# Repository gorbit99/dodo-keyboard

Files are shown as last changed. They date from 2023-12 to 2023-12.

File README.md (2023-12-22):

# Dodo

Dodo is a 60%, low-profile, wireless mechanical keyboard with per-key RGB
backlighting a display and a rotary encoder.

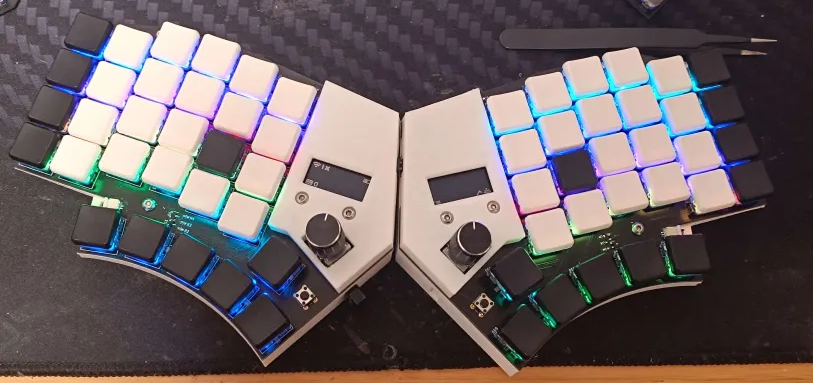
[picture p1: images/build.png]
The build


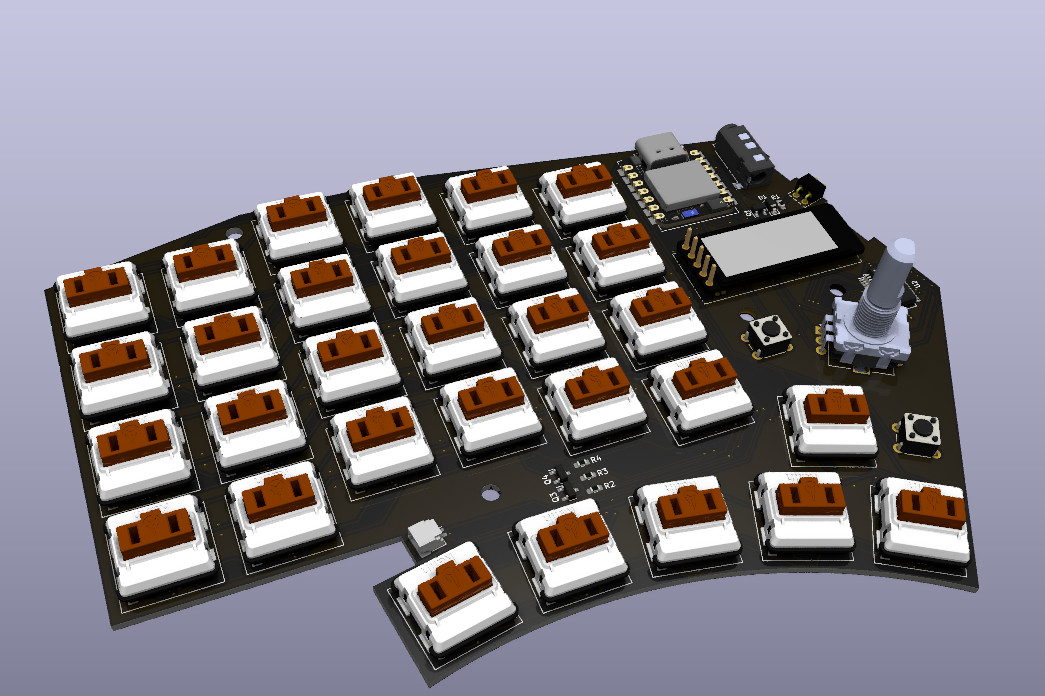
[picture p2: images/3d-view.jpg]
3D render of the PCB


## BOM

To build the PCB, you will need the following components for each side (so make
sure to get double of each):

| Part | Count | Link |
| --- | ----: | --- |
| B5817W Diode | 1 | [AliExpress](https://www.aliexpress.com/item/1005005615035910.html) |
| SK6812 MINI-E <sup>1</sup> | 30 | [AliExpress](https://www.aliexpress.com/item/1005005248164351.html) |
| 1N4148 SOD-123 | 30 | [AliExpress](https://www.aliexpress.com/item/1005005271390029.html) |
| SMD 3.5 mm jack <sup>2</sup> | 1 | [AliExpress](https://www.aliexpress.com/item/4000661908135.html) |
| 2 pin POGO connector <sup>2</sup> | 1 | [AliExpress](https://www.aliexpress.com/item/1005002006325514.html) |
| AO3401A <sup>1</sup> | 2 | [AliExpress](https://www.aliexpress.com/item/4001197981239.html) |
| 2N7002 <sup>1</sup> | 1 | [AliExpress](https://www.aliexpress.com/item/1005004759627915.html) |
| 10k Ω 0603 resistor <sup>1</sup>  | 3 | [AliExpress](https://www.aliexpress.com/item/1005006142628179.html) |
| 560 Ω 0603 resistor <sup>1</sup>  | 2 | [AliExpress](https://www.aliexpress.com/item/1005006142628179.html) |
| Momentary tactile switch | 2 | [AliExpress](https://www.aliexpress.com/item/1005004159746274.html) |
| EC11E style encoder <sup>3</sup>  | 1 | [AliExpress](https://www.aliexpress.com/item/1005002358274622.html) |
| Kailh Choc V1 | 30 | [AliExpress](https://www.aliexpress.com/item/1005004522163996.html) |
| XIAO BLE <sup>4</sup> | 1 | [AliExpress](https://www.aliexpress.com/item/1005004459618789.html) |
| MCP23S17SS | 1 | [AliExpress](https://www.aliexpress.com/item/1005004925908454.html) |
| nice!view <sup>5</sup> | 1 | [Official nice!view site](https://nicekeyboards.com/nice-view/) |
| SMD JST SH connector | 1 | [AliExpress](https://www.aliexpress.com/item/1005005682408443.html) |

All links are examples, I recommend looking around for better orders, and
especially switches that you like

1: The following components can be omitted, if you don't want RGB: SK6812
MINI-E, 1xAO3401A, 2N7002, 2x10k resistor, 1x560R resistor

2: These are for power delivery (only!) between the halves, so you can charge
them at the same time, but they are technically optional

3: Optional, if you don't need an encoder

4: You might find these as "XIAO NRF52840" or similar. There is also a sense
variant which is more expensive and not necessary

5: Optional, if you don't need a display

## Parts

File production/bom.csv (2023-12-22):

Designator | Footprint | Quantity | Value | LCSC Part #
BT1 | JST_SH_SM02B-SRSS-TB_1x02-1MP_P1.00mm_Horizontal_Double | 1 | Battery_Cell
D1 | D_SOD-123_Double | 1 | D_Schottky
D10, D12, D14, D16, D18, D2, D20, D22, D24, D26, D28, D30, D32, D34, D36, D38, D4, D40, D42, D44, D46, D48, D50, D52, D54, D56, D58, D6, D60, D8 | SK6812MINI-E_Double | 30 | SK6812MINI-E
D11, D13, D15, D17, D19, D21, D23, D25, D27, D29, D3, D31, D33, D35, D37, D39, D41, D43, D45, D47, D49, D5, D51, D53, D55, D57, D59, D61, D7, D9 | D_SOD-123_Double | 30 | 1N4148
H1, H2, H3, H4 | MountingHole_3.2mm_M3 | 4 | MountingHole
J1 | Jack_3.5mm_KoreanHropartsElec_PJ-320D-4A_Horizontal_Double | 1 | AudioJack4
J2 | Pogo2-Right-Angle | 1 | Conn_01x02_Socket
JP1, JP2, JP3, JP4 | Double_Sided_Jumper | 4 | SolderJumper_3_Open
Q1, Q4 | SOT-23_Double | 2 | AO3401A
Q3 | SOT-23_Double | 1 | 2N7002
R1, R3, R4 | 0603 | 3 | 10k
R2, R5 | 0603 | 2 | 560R
SW1, SW2 | SW_PUSH_6mm_Double | 2 | SW_Push
SW10, SW11, SW12, SW13, SW14, SW15, SW16, SW17, SW18, SW19, SW20, SW21, SW22, SW23, SW24, SW25, SW26, SW27, SW28, SW29, SW30, SW31, SW32, SW33, SW4, SW5, SW6, SW7, SW8, SW9 | SW_Kailh_Choc_V1_1.00u_Double | 30 | SW_Push
SW3 | RotaryEncoder_Alps_EC11E-Switch_Vertical_H20mm_Double | 1 | RotaryEncoder_Switch
U1 | XIAO-nRF52840_Double | 1 | XIAO_nRF52840
U2 | SSOP-28_5.3x10.2mm_P0.65mm_Double | 1 | MCP23S17_SS
U3 | NICE_VIEW | 1 | NICE_VIEW

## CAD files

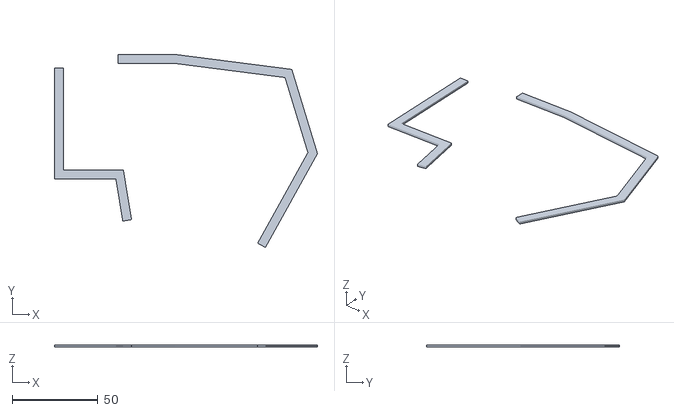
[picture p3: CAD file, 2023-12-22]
Case/DodoCasev3-Feet.stl
153.3 x 112.5 x 1.40

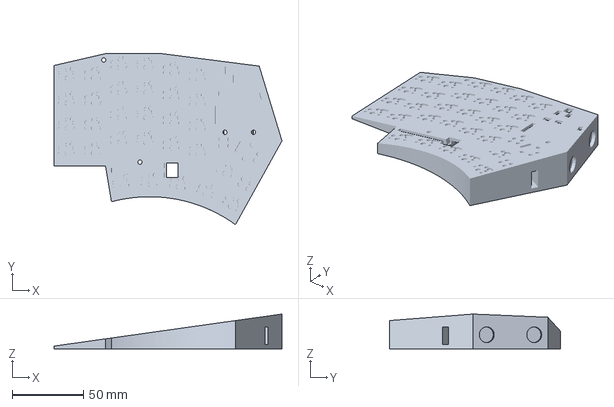
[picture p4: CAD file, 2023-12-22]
Case/DodoCasev3-Base.3mf
160.3 x 120.5 x 24.5 mm

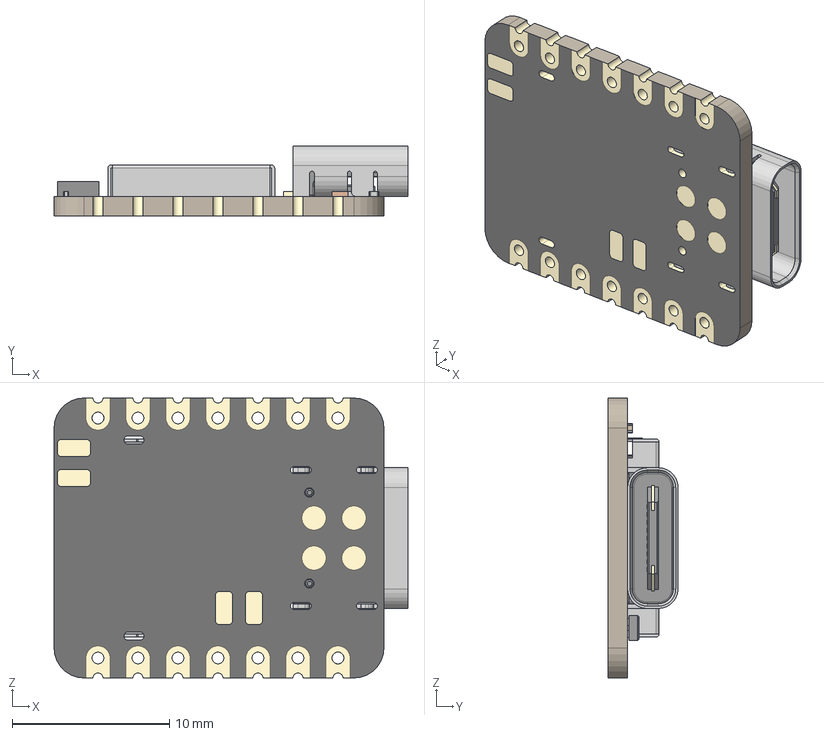
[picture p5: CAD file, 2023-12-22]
custom_parts/XIAO-nRF52840 v15.step
22.5 x 4.46 x 17.8 mm
BOSS-EXTRUDE14_8_
BOSS-EXTRUDE7_4_
BOSS-EXTRUDE7_3_
BOSS-EXTRUDE14_4_
BOSS-EXTRUDE14_2_
BOSS-EXTRUDE14_11_
BOSS-EXTRUDE7_7_
BOSS-EXTRUDE14_9_
BOSS-EXTRUDE14_3_
BOSS-EXTRUDE14_7_
MIRROR2
BOSS-EXTRUDE14_5_
BOSS-EXTRUDE14_12_
BOSS-EXTRUDE7_8_
BOSS-EXTRUDE7_1_
BOSS-EXTRUDE14_10_
BOSS-EXTRUDE7_9_
BOSS-EXTRUDE14_6_
BOSS-EXTRUDE14_1_
BOSS-EXTRUDE7_6_
BOSS-EXTRUDE7_2_
CUT-EXTRUDE5
BOSS-EXTRUDE7_5_
Shield
Pins
CAP x 2
ANT1
Silkscreen
CAP 3
LED
USR
2 v1

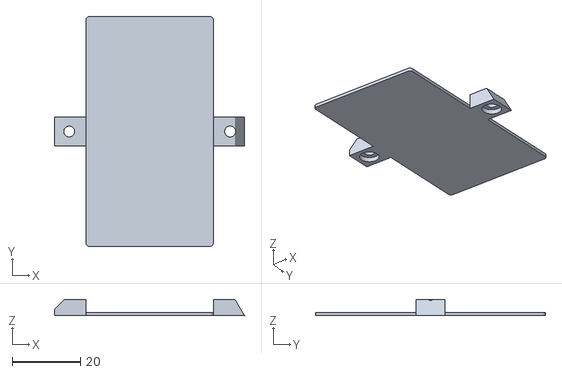
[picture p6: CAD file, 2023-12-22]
Case/DodoCasev3-BatteryCover.stl
55.5 x 67.2 x 4.80

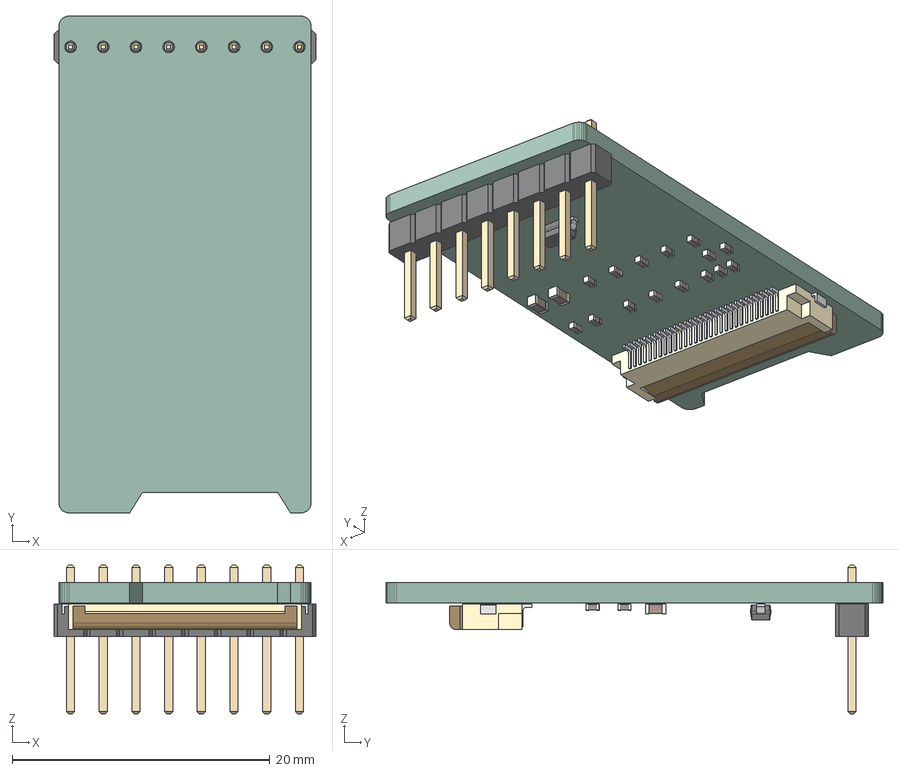
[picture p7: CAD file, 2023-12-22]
custom_parts/epaper-102.step
20.3 x 38.6 x 11.5 mm
_autosave-epaper-102 PCB

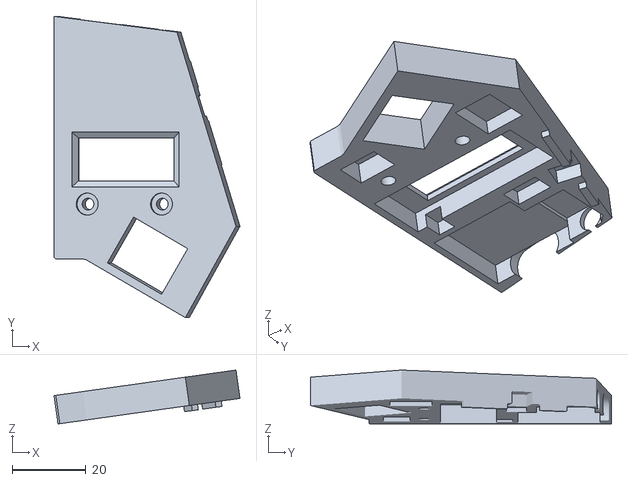
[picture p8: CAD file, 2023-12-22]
Case/DodoCasev3-Top.stl
50.4 x 81.5 x 14.6

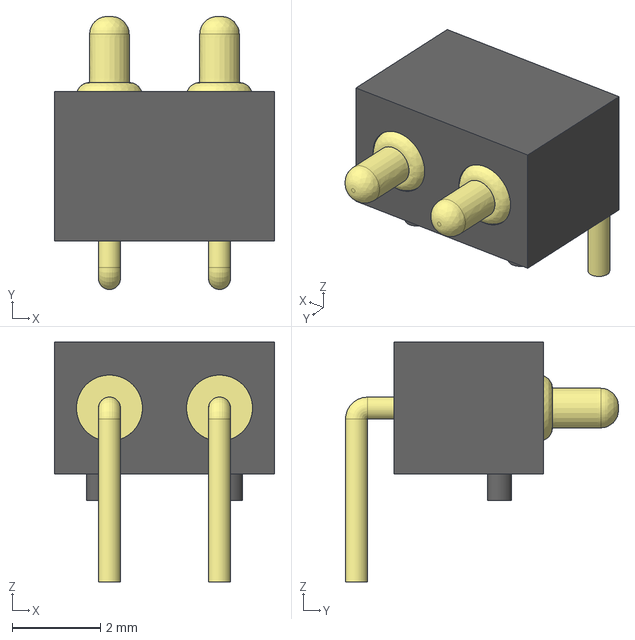
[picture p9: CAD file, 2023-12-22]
custom_parts/RightAnglePogo2_Male.step
5.00 x 6.20 x 5.45 mm
Pins

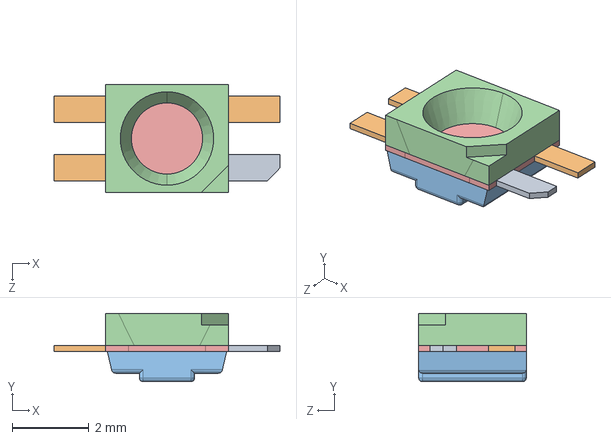
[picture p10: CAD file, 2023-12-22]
custom_parts/SK6812MINI-E.stp
5.88 x 1.78 x 2.80 mm

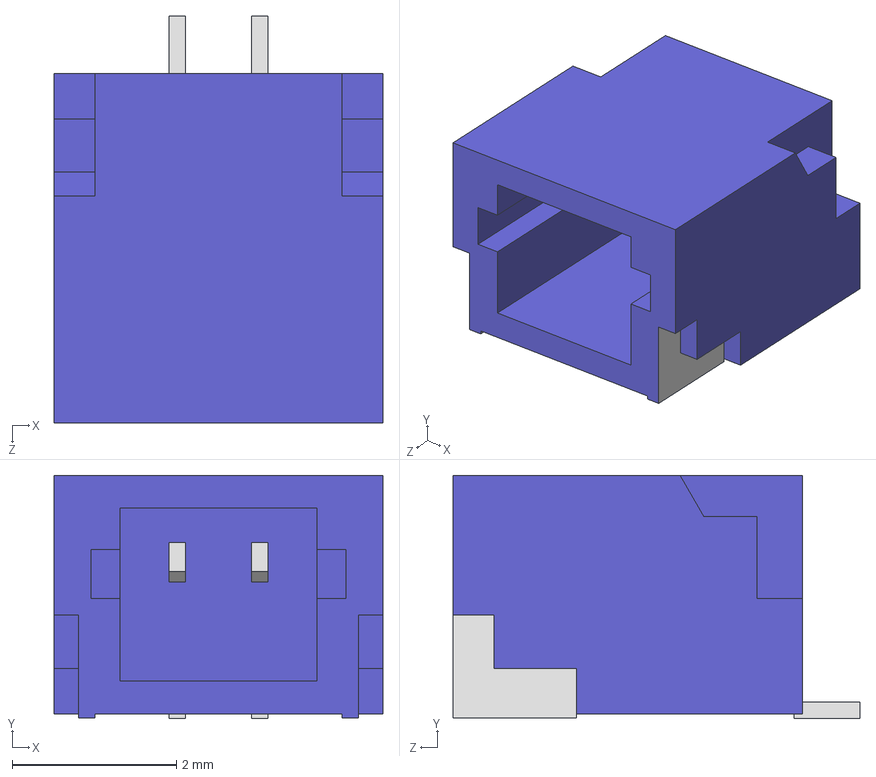
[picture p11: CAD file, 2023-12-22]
custom_parts/SM02B-SRSS-TB.STEP
4.00 x 2.96 x 4.95 mm

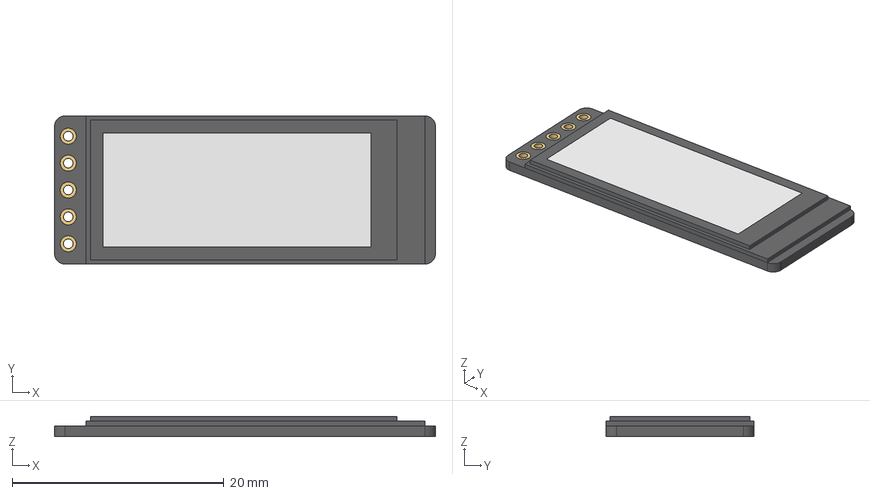
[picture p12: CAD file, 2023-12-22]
custom_parts/NiceView.step
36.0 x 14.0 x 1.90 mm
Screen
ScreenEdge
DisplayBody
Pins

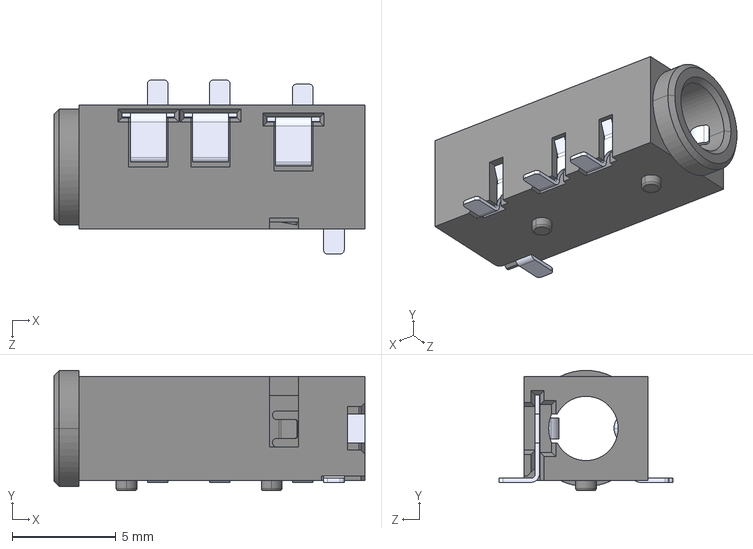
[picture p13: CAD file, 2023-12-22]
custom_parts/SJ2-3574A-SMT-TR--3DModel-STEP-56544.STEP
15.0 x 5.80 x 8.40 mm

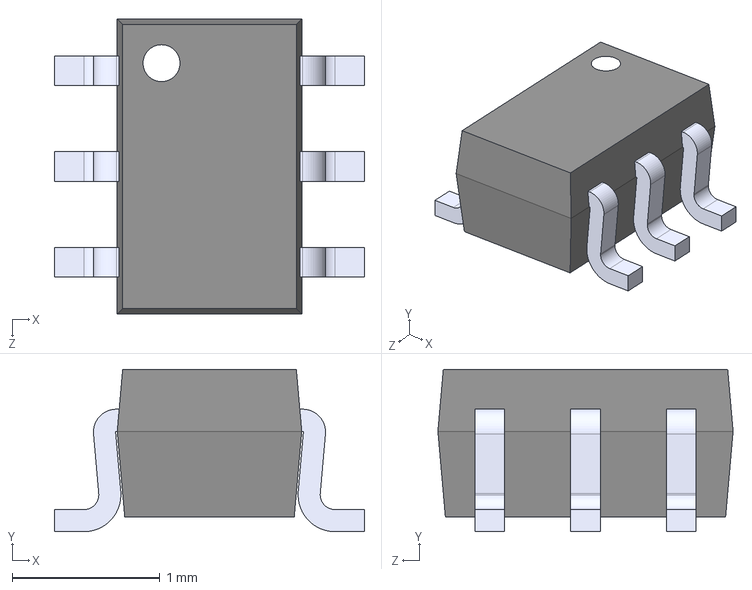
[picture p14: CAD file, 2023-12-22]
custom_parts/SMF05CT1G.step
2.10 x 1.10 x 2.00 mm

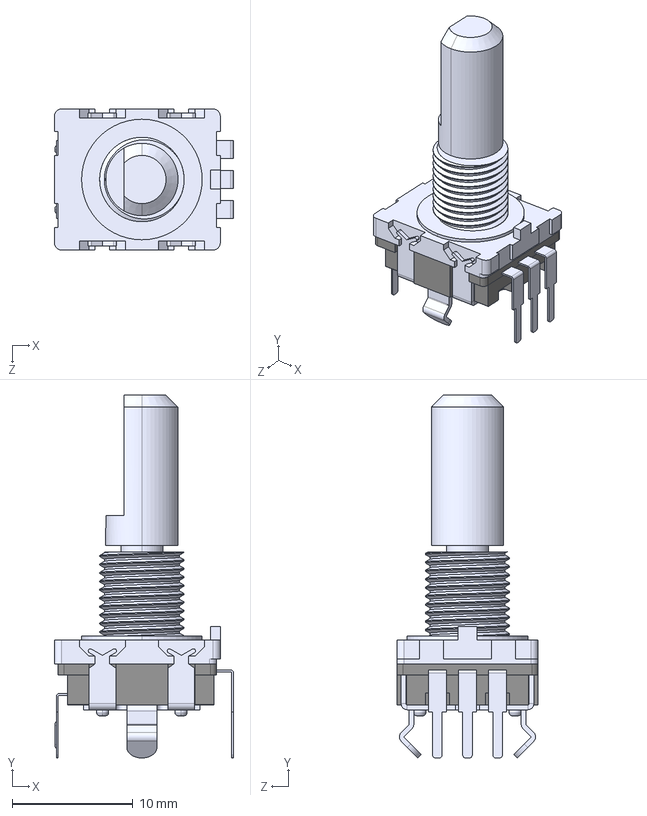
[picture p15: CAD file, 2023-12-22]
custom_parts/482016514001--3DModel-STEP-56544.STEP
14.9 x 30.1 x 11.7 mm

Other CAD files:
custom_parts/NiceView.stl
custom_parts/SM02B-SRSS-TB.step

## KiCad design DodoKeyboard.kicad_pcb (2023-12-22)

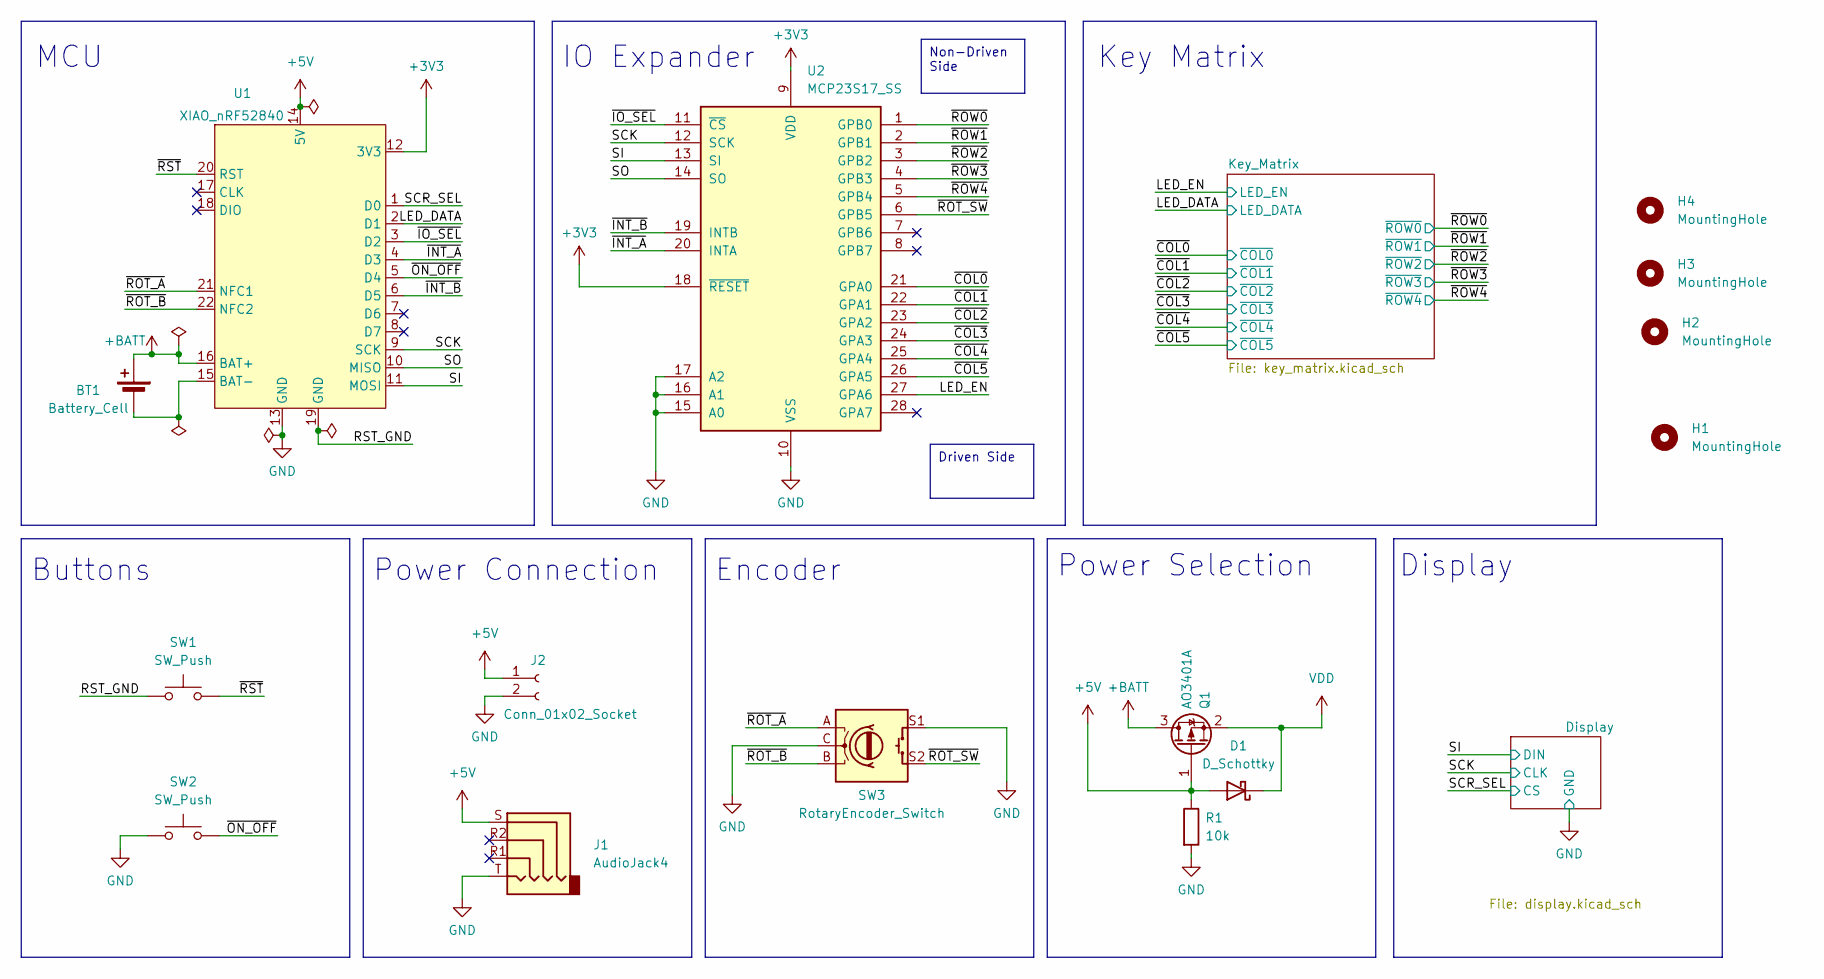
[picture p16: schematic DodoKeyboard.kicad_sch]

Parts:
BT1: Battery_Cell; JST_SH_SM02B-SRSS-TB_1x02-1MP_P1.00mm_Horizontal_Double
D1: D_Schottky; D_SOD-123_Double
H1, H2, H3, H4: MountingHole; MountingHole_3.2mm_M3
J1: AudioJack4; Jack_3.5mm_KoreanHropartsElec_PJ-320D-4A_Horizontal_Double
J2: Conn_01x02_Socket; Pogo2-Right-Angle
Q1: AO3401A; SOT-23_Double
R1: 10k; R_0603_1608Metric_Pad0.98x0.95mm_HandSolder_Double
SW1, SW2: SW_Push; SW_PUSH_6mm_Double
SW3: RotaryEncoder_Switch; RotaryEncoder_Alps_EC11E-Switch_Vertical_H20mm_Double
U1: XIAO_nRF52840; XIAO-nRF52840_Double
U2: MCP23S17_SS; SSOP-28_5.3x10.2mm_P0.65mm_Double

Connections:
+3V3: U1.12 (3V3), U2.9 (VDD), U2.18 (~RESET); also elsewhere on the board
+5V: D1.2 (A), J1.S, J2.1, Q1.1 (G), R1.1, U1.14 (5V)
+BATT: BT1.1 (+), Q1.3 (D), U1.16 (BAT+)
/LED_DATA: U1.2 (D1); also elsewhere on the board
/LED_EN: U2.27 (GPA6); also elsewhere on the board
/RST_GND: SW1.1, U1.19 (GND)
/SCK: U1.9 (SCK), U2.12 (SCK); also elsewhere on the board
/SCR_SEL: U1.1 (D0); also elsewhere on the board
/SI: U1.11 (MOSI), U2.13 (SI); also elsewhere on the board
/SO: U1.10 (MISO), U2.14 (SO)
/~COL0: U2.21 (GPA0); also elsewhere on the board
/~COL1: U2.22 (GPA1); also elsewhere on the board
/~COL2: U2.23 (GPA2); also elsewhere on the board
/~COL3: U2.24 (GPA3); also elsewhere on the board
/~COL4: U2.25 (GPA4); also elsewhere on the board
/~COL5: U2.26 (GPA5); also elsewhere on the board
/~INT_A: U1.4 (D3), U2.20 (INTA)
/~INT_B: U1.6 (D5), U2.19 (INTB)
/~IO_SEL: U1.3 (D2), U2.11 (~CS)
/~ON_OFF: SW2.2, U1.5 (D4)
/~ROT_A: SW3.A, U1.21 (NFC1)
/~ROT_B: SW3.B, U1.22 (NFC2)
/~ROT_SW: SW3.S2, U2.6 (GPB5)
/~ROW0: U2.1 (GPB0); also elsewhere on the board
/~ROW1: U2.2 (GPB1); also elsewhere on the board
/~ROW2: U2.3 (GPB2); also elsewhere on the board
/~ROW3: U2.4 (GPB3); also elsewhere on the board
/~ROW4: U2.5 (GPB4); also elsewhere on the board
/~RST: SW1.2, U1.20 (RST)
GND: J1.T, J2.2, R1.2, SW2.1, SW3.C, SW3.S1, U1.13 (GND), U2.10 (VSS), U2.15 (A0), U2.16 (A1), U2.17 (A2); also elsewhere on the board
unnamed: BT1.2 (-), U1.15 (BAT-)
VDD: D1.1 (K), Q1.2 (S); also elsewhere on the board

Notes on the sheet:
Non-Driven Side
Driven Side
Display
Power Connection
Buttons
MCU
Encoder
Key Matrix
Power Selection
IO Expander

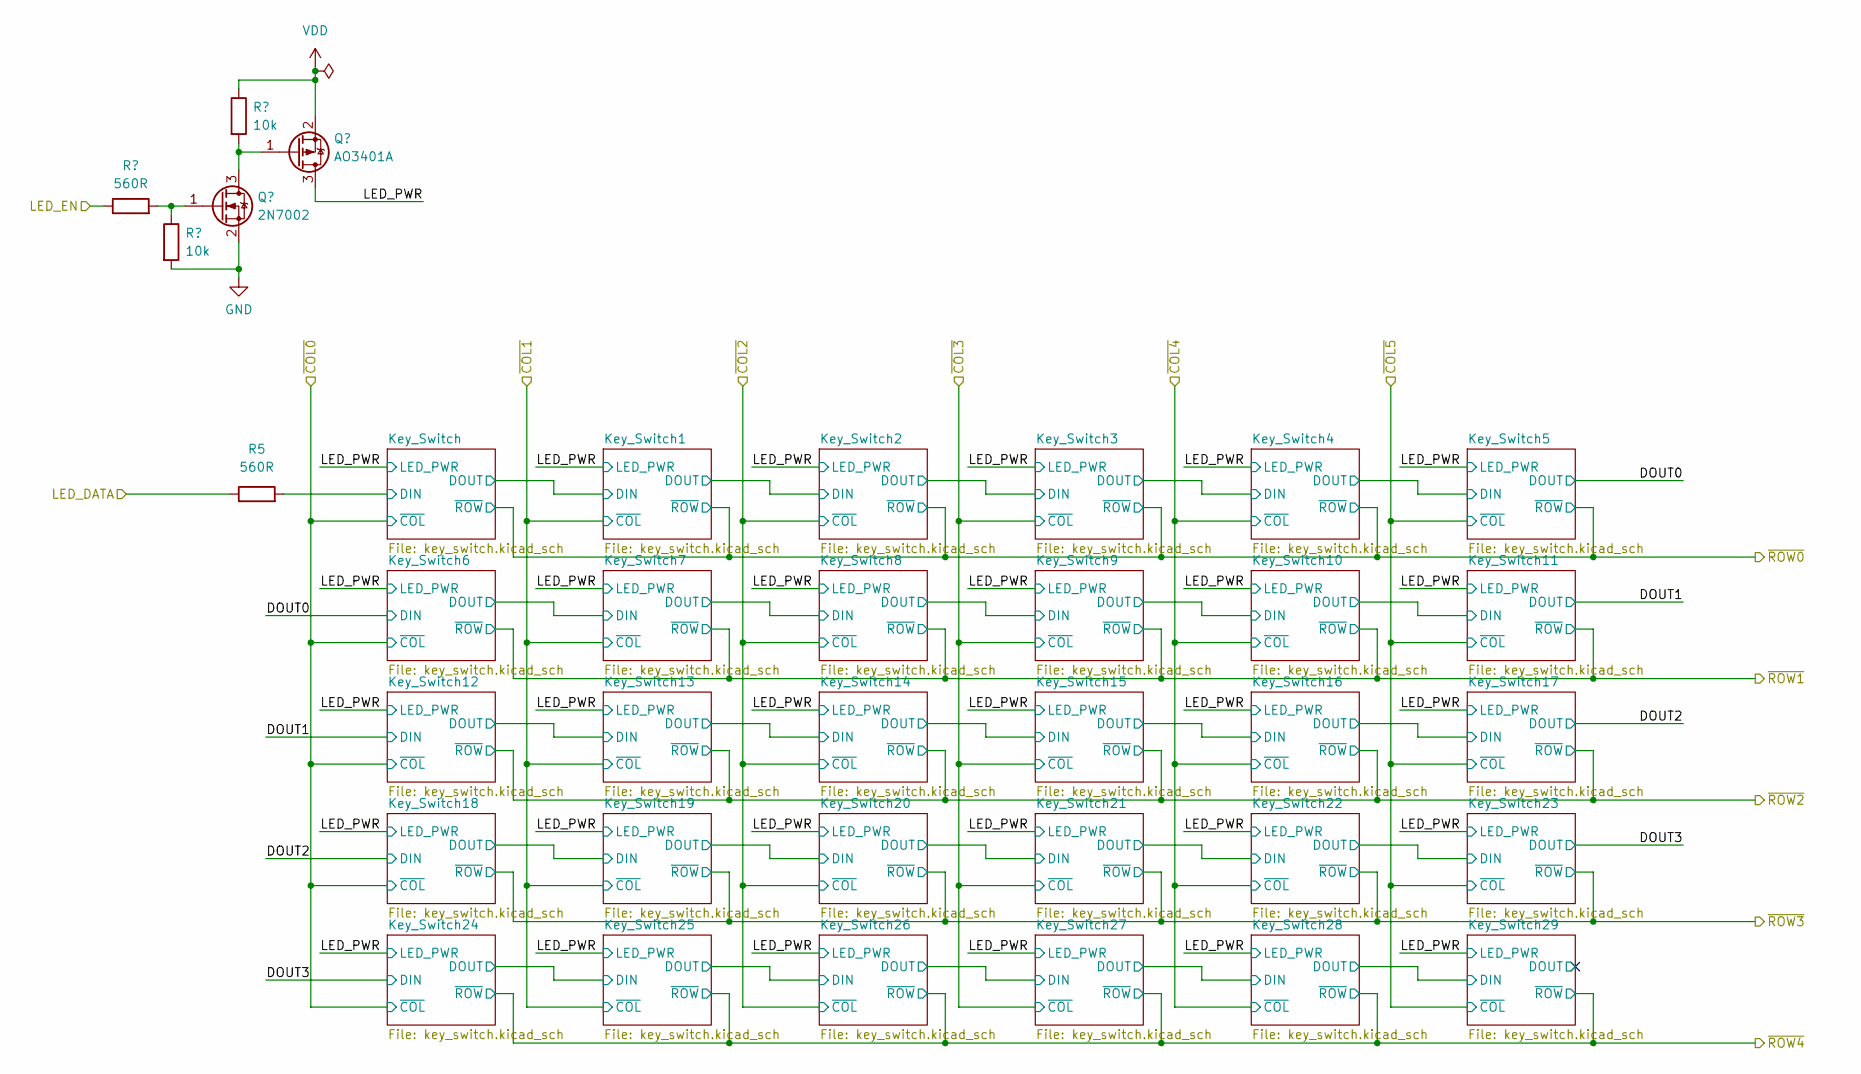
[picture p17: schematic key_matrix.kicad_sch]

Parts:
Q3: 2N7002; SOT-23_Double
Q4: AO3401A; SOT-23_Double
R2, R5: 560R; R_0603_1608Metric_Pad0.98x0.95mm_HandSolder_Double
R3, R4: 10k; R_0603_1608Metric_Pad0.98x0.95mm_HandSolder_Double

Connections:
/Key_Matrix/Key_Switch/DIN: R5.2; also elsewhere on the board
/Key_Matrix/LED_PWR: Q4.3 (D); also elsewhere on the board
/LED_DATA: R5.1; also elsewhere on the board
/LED_EN: R2.1; also elsewhere on the board
GND: Q3.2 (S), R3.2; also elsewhere on the board
unnamed: Q3.3 (D), Q4.1 (G), R4.2
unnamed: Q3.1 (G), R2.2, R3.1
VDD: Q4.2 (S), R4.1; also elsewhere on the board

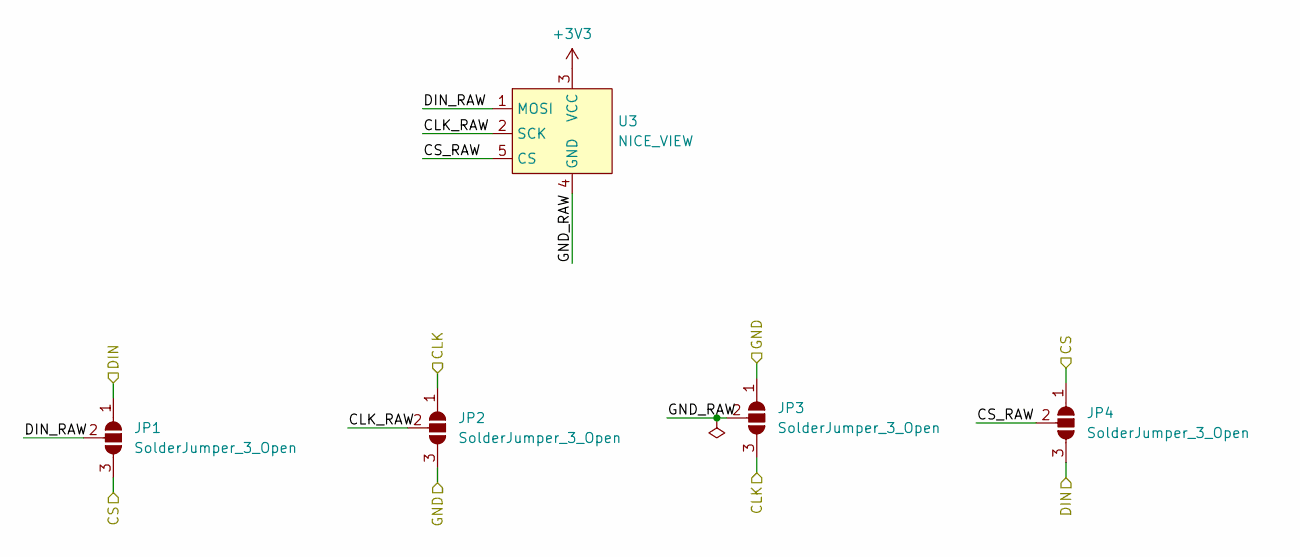
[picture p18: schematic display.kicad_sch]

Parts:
JP1, JP2, JP3, JP4: SolderJumper_3_Open; Double_Sided_Jumper
U3: NICE_VIEW

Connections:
+3V3: U3.3 (VCC); also elsewhere on the board
/Display/CLK_RAW: JP2.2 (C), U3.2 (SCK)
/Display/CS_RAW: JP4.2 (C), U3.5 (CS)
/Display/DIN_RAW: JP1.2 (C), U3.1 (MOSI)
/Display/GND_RAW: JP3.2 (C), U3.4 (GND)
/SCK: JP2.1 (A), JP3.3 (B); also elsewhere on the board
/SCR_SEL: JP1.3 (B), JP4.1 (A); also elsewhere on the board
/SI: JP1.1 (A), JP4.3 (B); also elsewhere on the board
GND: JP2.3 (B), JP3.1 (A); also elsewhere on the board

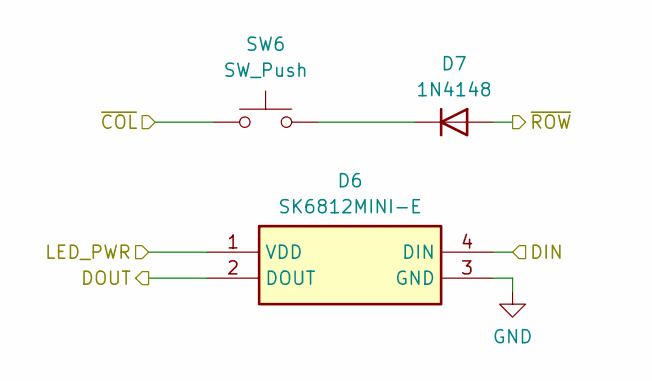
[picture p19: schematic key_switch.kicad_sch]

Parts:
D6: SK6812MINI-E; SK6812MINI-E_Double; Manufacturer_Part_Number SK6812MINI-E
D7: 1N4148; D_SOD-123_Double
SW6: SW_Push; SW_Kailh_Choc_V1_1.00u_Double

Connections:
/Key_Matrix/Key_Switch1/DOUT: D6.4 (DIN); also elsewhere on the board
/Key_Matrix/Key_Switch2/DOUT: D6.2 (DOUT); also elsewhere on the board
/Key_Matrix/LED_PWR: D6.1 (VDD); also elsewhere on the board
/~COL2: SW6.1; also elsewhere on the board
/~ROW0: D7.2 (A); also elsewhere on the board
GND: D6.3 (GND); also elsewhere on the board
unnamed: D7.1 (K), SW6.2

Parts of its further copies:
D2, D4, D8, D10, D12, D14, D16, D18, D20, D22, D24, D26, D28, D30, D32, D34, D36, D38, D40, D42, D44, D46, D48, D50, D52, D54, D56, D58, D60: SK6812MINI-E; SK6812MINI-E_Double; Manufacturer_Part_Number SK6812MINI-E
D3, D5, D9, D11, D13, D15, D17, D19, D21, D23, D25, D27, D29, D31, D33, D35, D37, D39, D41, D43, D45, D47, D49, D51, D53, D55, D57, D59, D61: 1N4148; D_SOD-123_Double
SW4, SW5, SW7, SW8, SW9, SW10, SW11, SW12, SW13, SW14, SW15, SW16, SW17, SW18, SW19, SW20, SW21, SW22, SW23, SW24, SW25, SW26, SW27, SW28, SW29, SW30, SW31, SW32, SW33: SW_Push; SW_Kailh_Choc_V1_1.00u_Double

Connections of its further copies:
/Key_Matrix/DOUT0: D12.2 (DOUT), D14.4 (DIN)
/Key_Matrix/DOUT1: D24.2 (DOUT), D26.4 (DIN)
/Key_Matrix/DOUT2: D36.2 (DOUT), D38.4 (DIN)
/Key_Matrix/DOUT3: D48.2 (DOUT), D50.4 (DIN)
/Key_Matrix/Key_Switch1/DOUT: D4.2 (DOUT); also elsewhere on the board
/Key_Matrix/Key_Switch2/DOUT: D8.4 (DIN); also elsewhere on the board
/Key_Matrix/Key_Switch3/DOUT: D8.2 (DOUT), D10.4 (DIN)
/Key_Matrix/Key_Switch4/DOUT: D10.2 (DOUT), D12.4 (DIN)
/Key_Matrix/Key_Switch6/DOUT: D14.2 (DOUT), D16.4 (DIN)
/Key_Matrix/Key_Switch7/DOUT: D16.2 (DOUT), D18.4 (DIN)
/Key_Matrix/Key_Switch8/DOUT: D18.2 (DOUT), D20.4 (DIN)
/Key_Matrix/Key_Switch10/DIN: D20.2 (DOUT), D22.4 (DIN)
/Key_Matrix/Key_Switch10/DOUT: D22.2 (DOUT), D24.4 (DIN)
/Key_Matrix/Key_Switch12/DOUT: D26.2 (DOUT), D28.4 (DIN)
/Key_Matrix/Key_Switch13/DOUT: D28.2 (DOUT), D30.4 (DIN)
/Key_Matrix/Key_Switch14/DOUT: D30.2 (DOUT), D32.4 (DIN)
/Key_Matrix/Key_Switch15/DOUT: D32.2 (DOUT), D34.4 (DIN)
/Key_Matrix/Key_Switch16/DOUT: D34.2 (DOUT), D36.4 (DIN)
/Key_Matrix/Key_Switch18/DOUT: D38.2 (DOUT), D40.4 (DIN)
/Key_Matrix/Key_Switch19/DOUT: D40.2 (DOUT), D42.4 (DIN)
/Key_Matrix/Key_Switch20/DOUT: D42.2 (DOUT), D44.4 (DIN)
/Key_Matrix/Key_Switch21/DOUT: D44.2 (DOUT), D46.4 (DIN)
/Key_Matrix/Key_Switch22/DOUT: D46.2 (DOUT), D48.4 (DIN)
/Key_Matrix/Key_Switch24/DOUT: D50.2 (DOUT), D52.4 (DIN)
/Key_Matrix/Key_Switch25/DOUT: D52.2 (DOUT), D54.4 (DIN)
/Key_Matrix/Key_Switch26/DOUT: D54.2 (DOUT), D56.4 (DIN)
/Key_Matrix/Key_Switch27/DOUT: D56.2 (DOUT), D58.4 (DIN)
/Key_Matrix/Key_Switch28/DOUT: D58.2 (DOUT), D60.4 (DIN)
/Key_Matrix/Key_Switch29/DOUT: D60.2 (DOUT)
/Key_Matrix/Key_Switch/DIN: D2.4 (DIN); also elsewhere on the board
/Key_Matrix/Key_Switch/DOUT: D2.2 (DOUT), D4.4 (DIN)
/Key_Matrix/LED_PWR: D2.1 (VDD), D4.1 (VDD), D8.1 (VDD), D10.1 (VDD), D12.1 (VDD), D14.1 (VDD), D16.1 (VDD), D18.1 (VDD), D20.1 (VDD), D22.1 (VDD), D24.1 (VDD), D26.1 (VDD), D28.1 (VDD), D30.1 (VDD), D32.1 (VDD), D34.1 (VDD), D36.1 (VDD), D38.1 (VDD), D40.1 (VDD), D42.1 (VDD), D44.1 (VDD), D46.1 (VDD), D48.1 (VDD), D50.1 (VDD), D52.1 (VDD), D54.1 (VDD), D56.1 (VDD), D58.1 (VDD), D60.1 (VDD); also elsewhere on the board
/~COL0: SW4.1, SW10.1, SW16.1, SW22.1, SW28.1; also elsewhere on the board
/~COL1: SW5.1, SW11.1, SW17.1, SW23.1, SW29.1; also elsewhere on the board
/~COL2: SW12.1, SW18.1, SW24.1, SW30.1; also elsewhere on the board
/~COL3: SW7.1, SW13.1, SW19.1, SW25.1, SW31.1; also elsewhere on the board
/~COL4: SW8.1, SW14.1, SW20.1, SW26.1, SW32.1; also elsewhere on the board
/~COL5: SW9.1, SW15.1, SW21.1, SW27.1, SW33.1; also elsewhere on the board
/~ROW0: D3.2 (A), D5.2 (A), D9.2 (A), D11.2 (A), D13.2 (A); also elsewhere on the board
/~ROW1: D15.2 (A), D17.2 (A), D19.2 (A), D21.2 (A), D23.2 (A), D25.2 (A); also elsewhere on the board
/~ROW2: D27.2 (A), D29.2 (A), D31.2 (A), D33.2 (A), D35.2 (A), D37.2 (A); also elsewhere on the board
/~ROW3: D39.2 (A), D41.2 (A), D43.2 (A), D45.2 (A), D47.2 (A), D49.2 (A); also elsewhere on the board
/~ROW4: D51.2 (A), D53.2 (A), D55.2 (A), D57.2 (A), D59.2 (A), D61.2 (A); also elsewhere on the board
GND: D2.3 (GND), D4.3 (GND), D8.3 (GND), D10.3 (GND), D12.3 (GND), D14.3 (GND), D16.3 (GND), D18.3 (GND), D20.3 (GND), D22.3 (GND), D24.3 (GND), D26.3 (GND), D28.3 (GND), D30.3 (GND), D32.3 (GND), D34.3 (GND), D36.3 (GND), D38.3 (GND), D40.3 (GND), D42.3 (GND), D44.3 (GND), D46.3 (GND), D48.3 (GND), D50.3 (GND), D52.3 (GND), D54.3 (GND), D56.3 (GND), D58.3 (GND), D60.3 (GND); also elsewhere on the board
unnamed: D3.1 (K), SW4.2
unnamed: D5.1 (K), SW5.2
unnamed: D9.1 (K), SW7.2
unnamed: D11.1 (K), SW8.2
unnamed: D13.1 (K), SW9.2
unnamed: D15.1 (K), SW10.2
unnamed: D17.1 (K), SW11.2
unnamed: D19.1 (K), SW12.2
unnamed: D21.1 (K), SW13.2
unnamed: D23.1 (K), SW14.2
unnamed: D25.1 (K), SW15.2
unnamed: D27.1 (K), SW16.2
unnamed: D29.1 (K), SW17.2
unnamed: D31.1 (K), SW18.2
unnamed: D33.1 (K), SW19.2
unnamed: D35.1 (K), SW20.2
unnamed: D37.1 (K), SW21.2
unnamed: D39.1 (K), SW22.2
unnamed: D41.1 (K), SW23.2
unnamed: D43.1 (K), SW24.2
unnamed: D45.1 (K), SW25.2
unnamed: D47.1 (K), SW26.2
unnamed: D49.1 (K), SW27.2
unnamed: D51.1 (K), SW28.2
unnamed: D53.1 (K), SW29.2
unnamed: D55.1 (K), SW30.2
unnamed: D57.1 (K), SW31.2
unnamed: D59.1 (K), SW32.2
unnamed: D61.1 (K), SW33.2

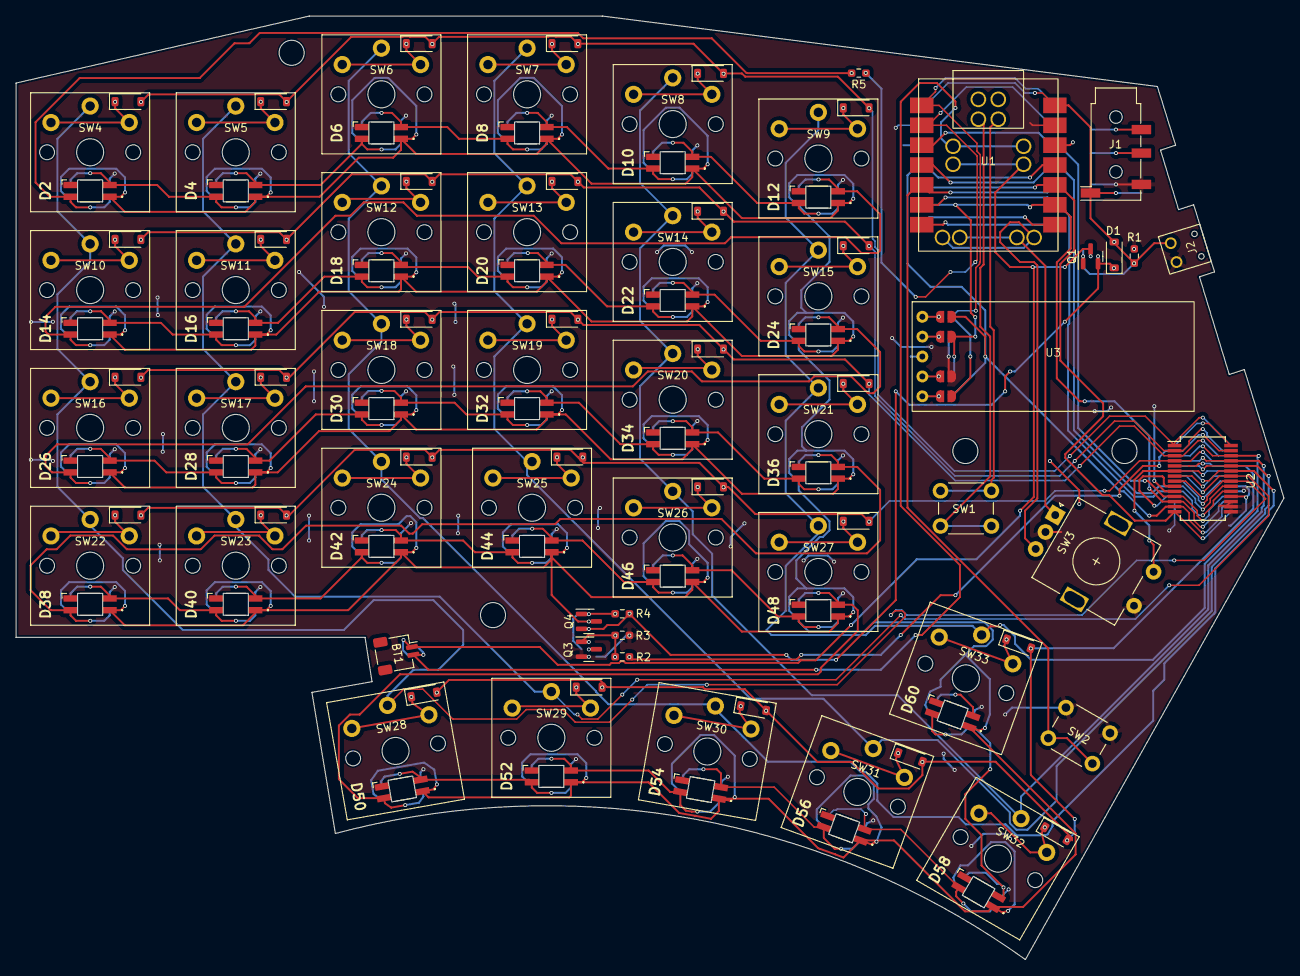
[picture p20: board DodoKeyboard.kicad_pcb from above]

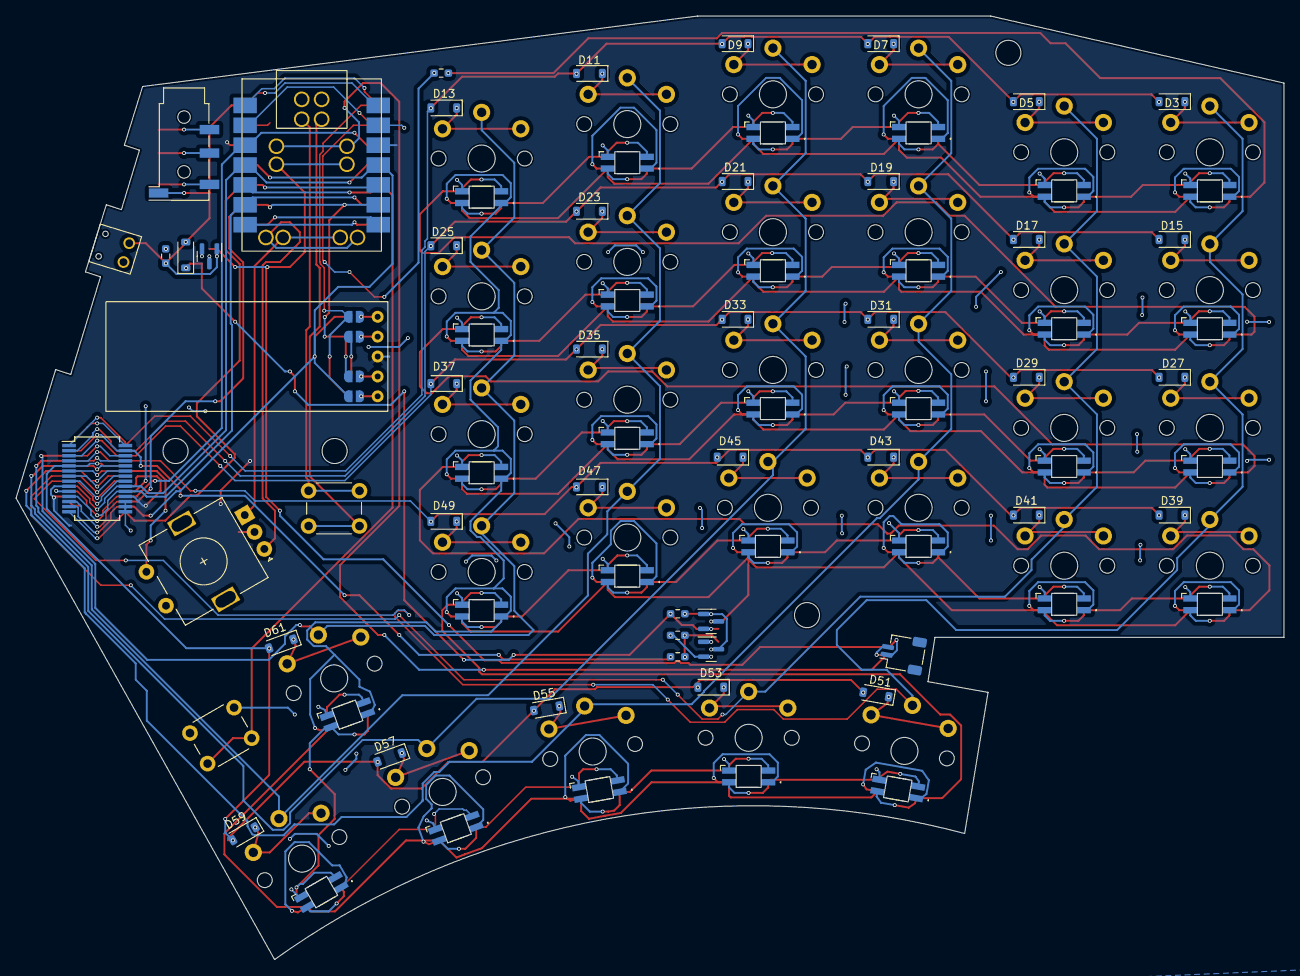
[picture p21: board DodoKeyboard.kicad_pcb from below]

Board: 2 copper layers, 161.9 x 120.5 mm, 116 parts (30 on the bottom side), 99 nets.
